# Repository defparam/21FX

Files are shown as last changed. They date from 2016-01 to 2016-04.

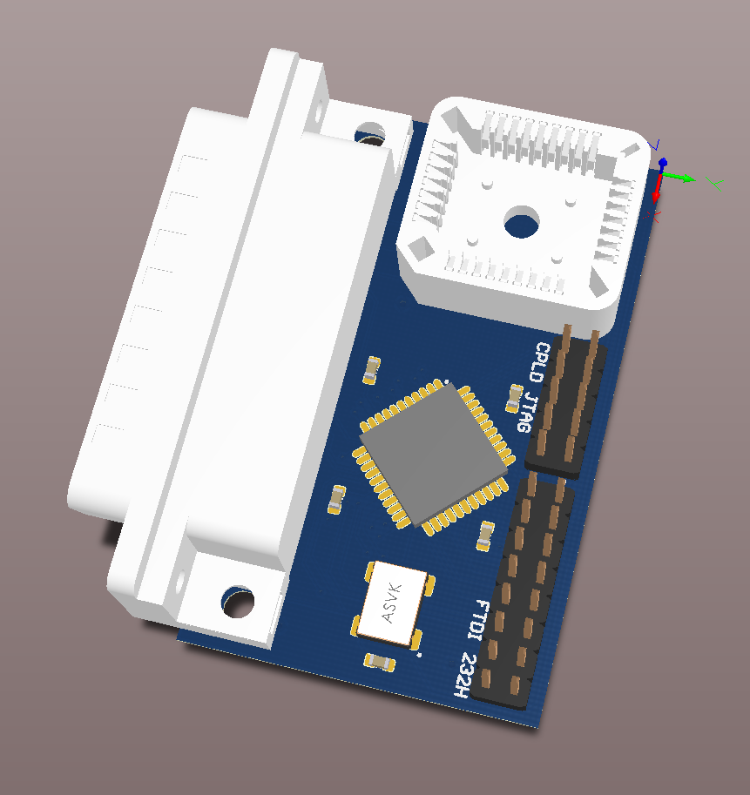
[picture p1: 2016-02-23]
photos/sh_3dt3.png

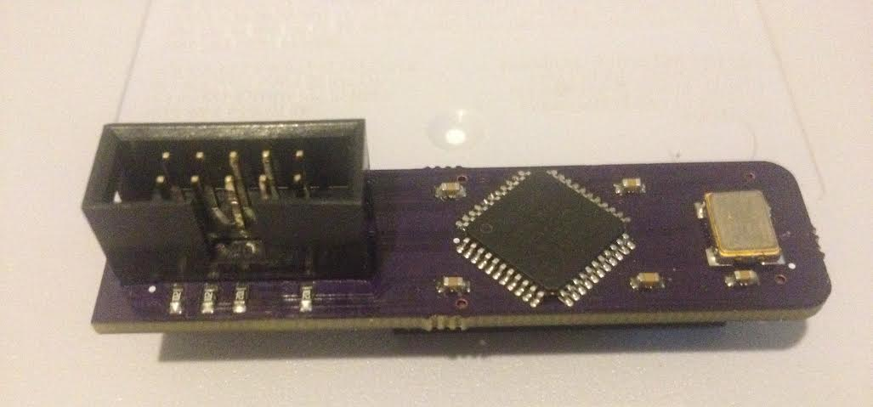
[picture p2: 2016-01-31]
photos/board_1.bmp

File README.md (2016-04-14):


# 21FX - An SNES Primary Bootloader (formerly SNES-Hook) 
This project includes Altium and verilog design files for an SNES CPLD 
expansion port to perform a simple reset hijacking and present a primary 
bootloader for the SNES to use. The bootloader is intended to be used in
conjunction with byuu's Controller Port Serial Cable for uploading
executable code into WRAM.

Updates
---------------------------------------------------------------------
4/14/2016 - REV C boards back and tested working. The boards now conform
to the new SNES expansion bridge DB-25 connector. byuu has produced the IPLROM
which is programmed to the EEPROM. Couple of issues with some power off noise
to the 232H but nothing serious

21FX - Rev C (Full Release)
---------------------------------------------------------------------
In this release we have changed the entire form factor of the board.
The board now conforms to a DB-25 connector and will mate to the new
SNES expansion bridge. We have also kept the same size CPLD and decided
to keep the IPLROM on a separate microchip 5v parallel eeprom chip. Lastly
the project no longer targets byuu's USART board. It instead has the connector
footprint for the Adafruit FT232H USB transceiver board. The IPLROM targets
all back and forth communication through this device.

SNES-Hook v1.1 REV B (Full Release)
---------------------------------------------------------------------
Updated top verilog file to include 2 more force/glitch outputs for
providing extra current strength on the glitched lines.

SNES-Hook v1.0 (Full Release)
---------------------------------------------------------------------
This a preliminary full release of SNES-Hook. In the release is the 
verilog files, Altium board design files and the quartus project which 
targets the MAX7000S CPLD on the SNES-Hook board.

@defparam

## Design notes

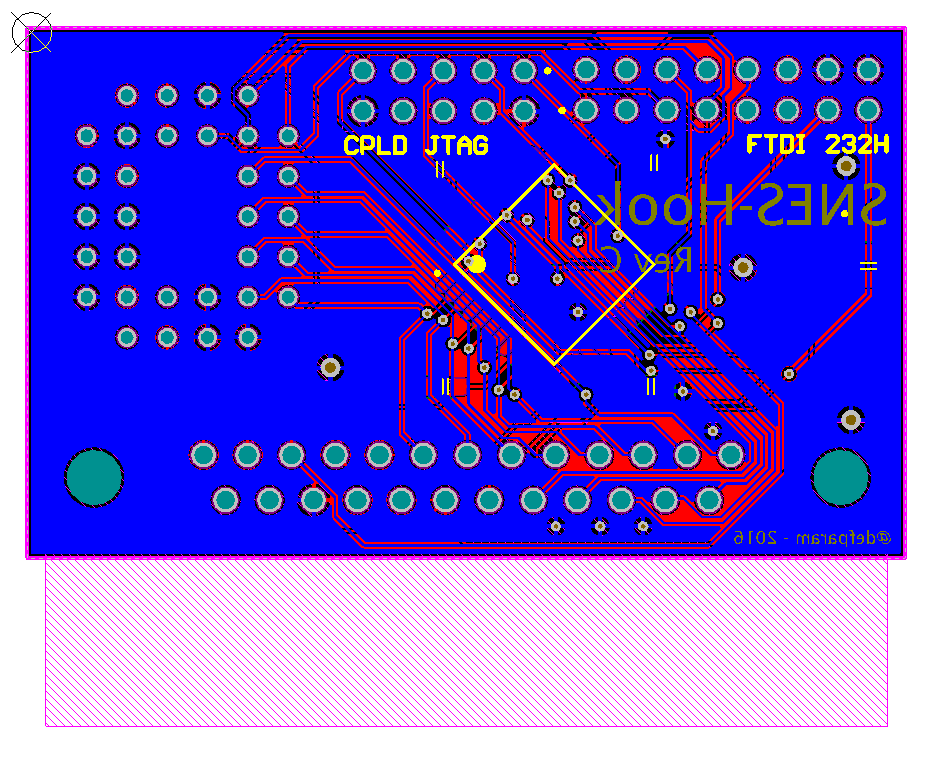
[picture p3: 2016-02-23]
photos/sh_b.png

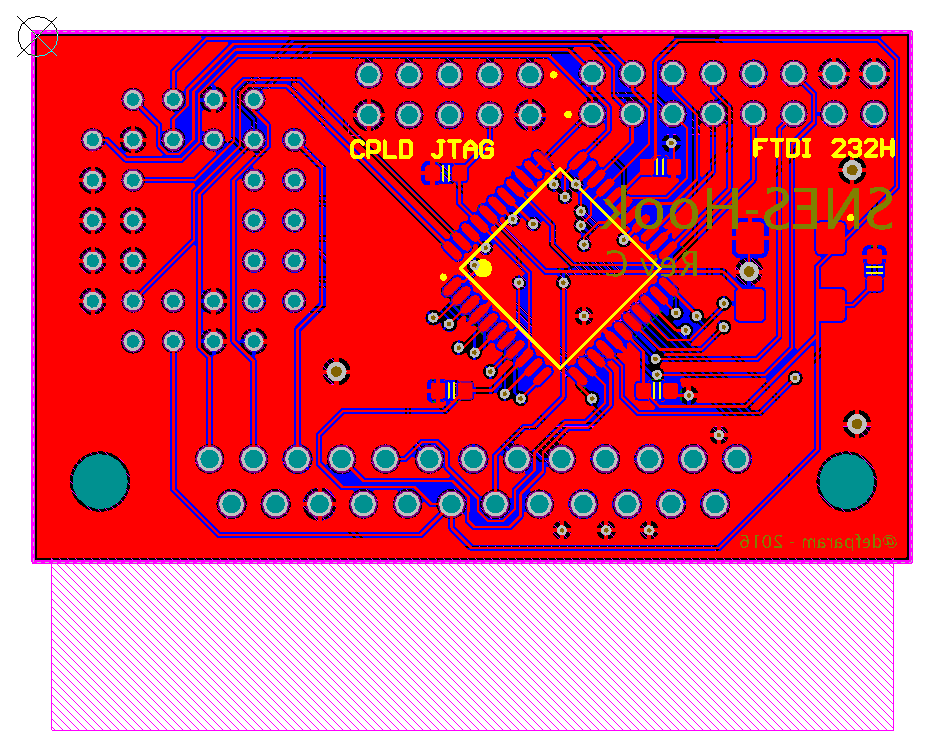
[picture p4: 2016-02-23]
photos/sh_t.png

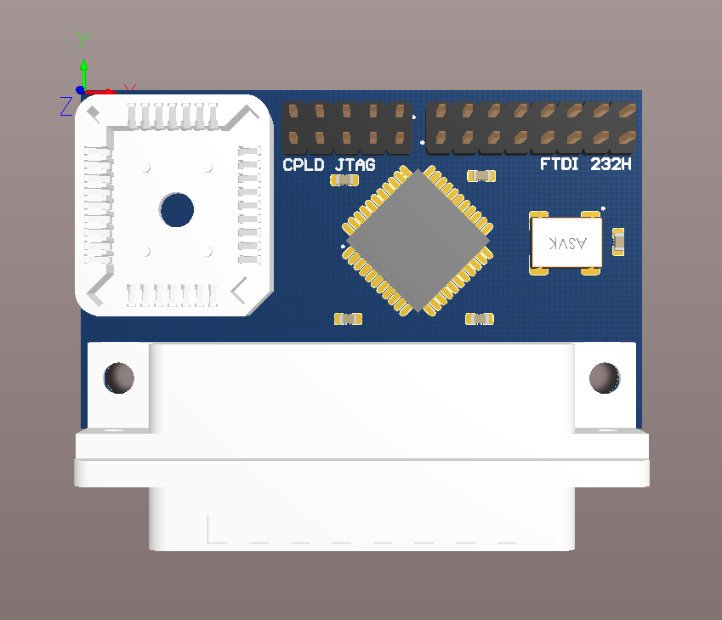
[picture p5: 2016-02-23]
photos/sh_3dt.png

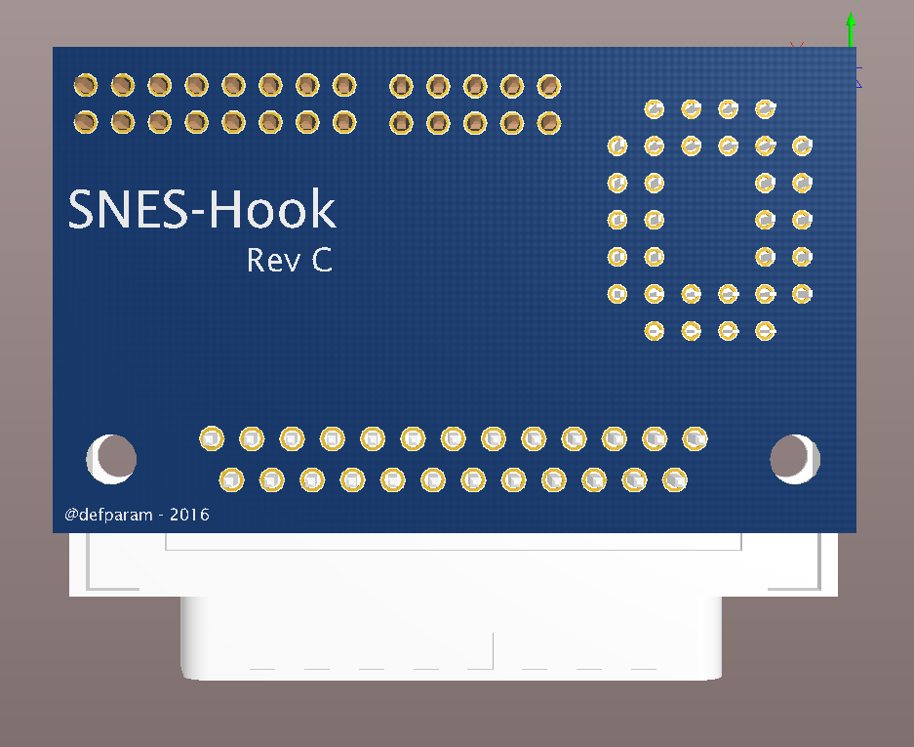
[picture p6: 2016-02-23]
photos/sh_3dt4.png

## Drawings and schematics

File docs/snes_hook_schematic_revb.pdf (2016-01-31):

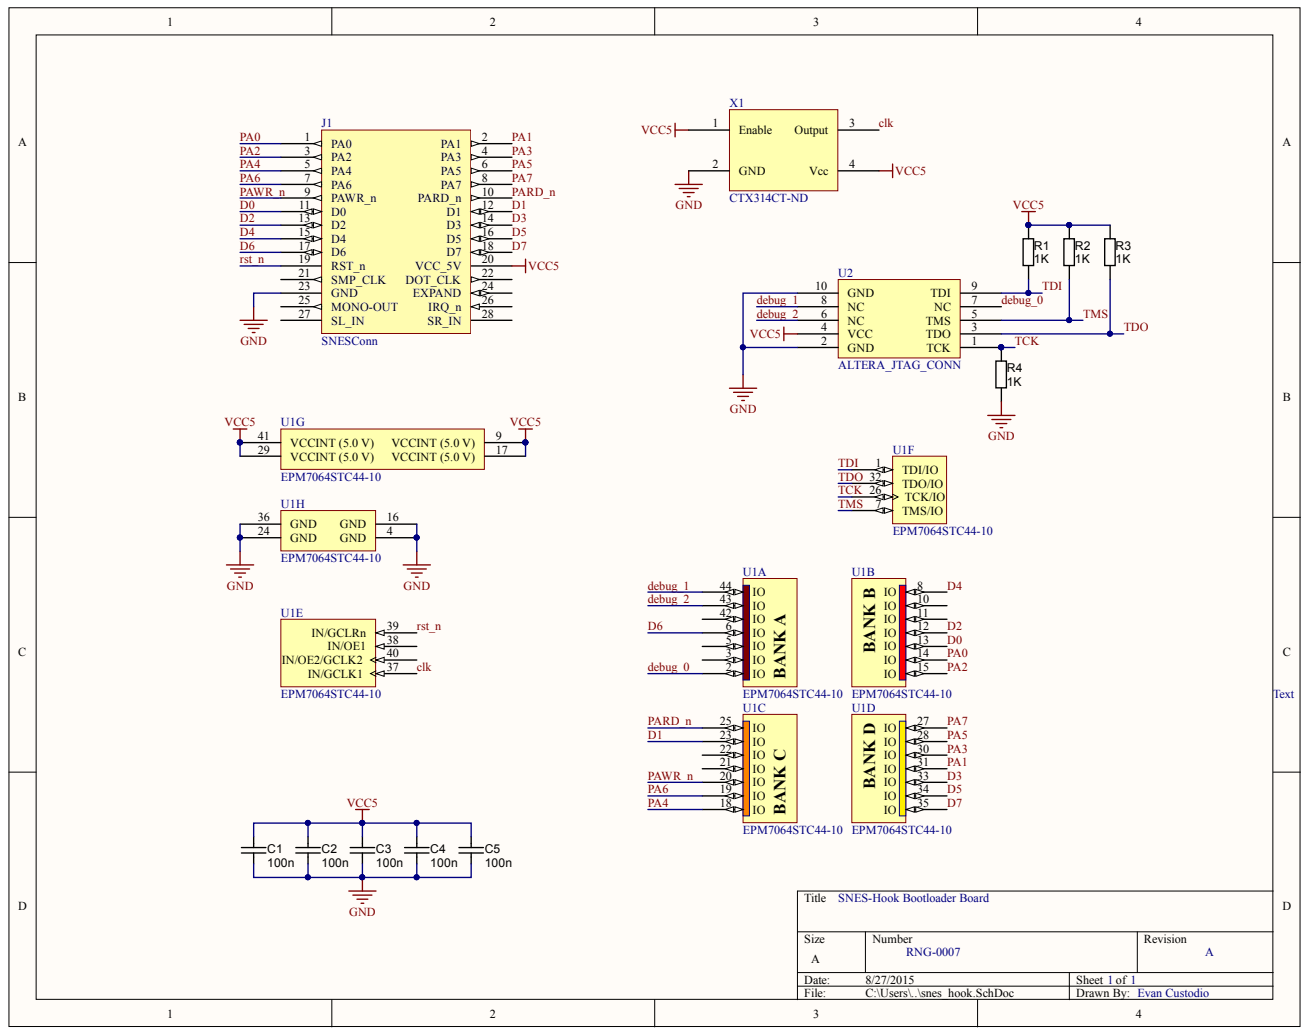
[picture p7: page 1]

SNES-Hook Bootloader Board

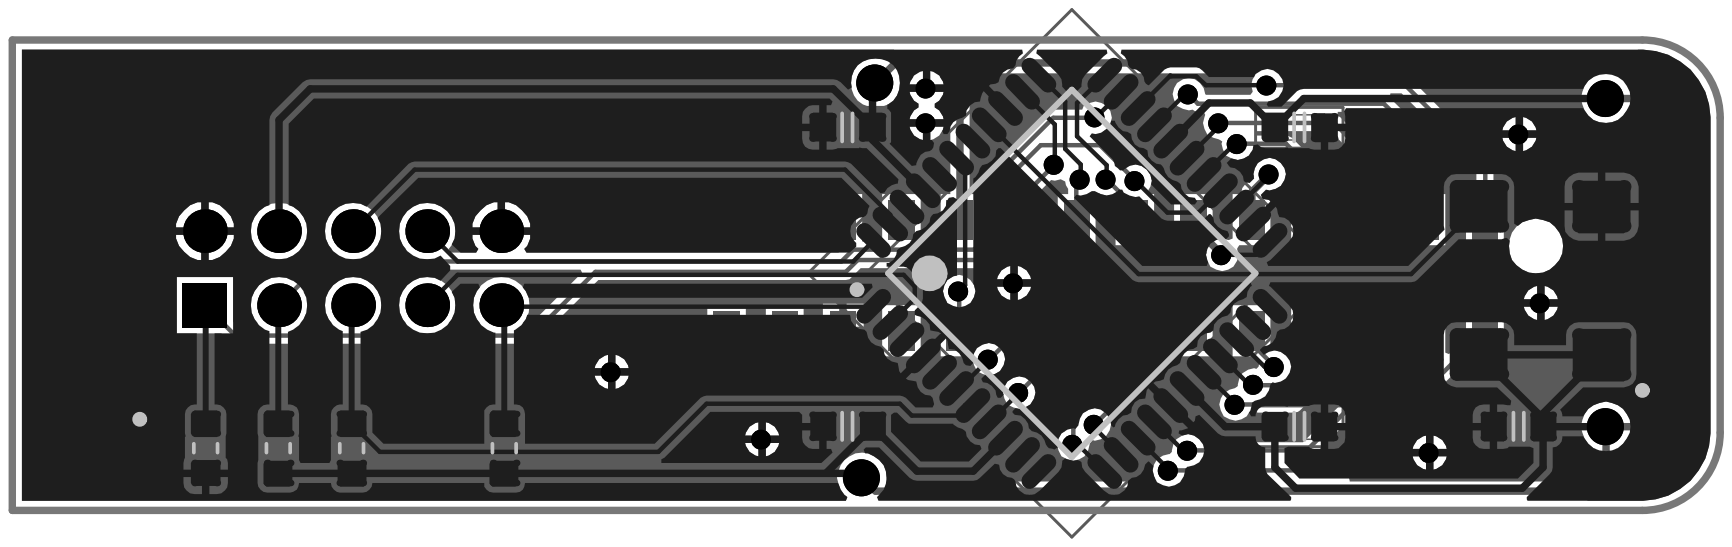
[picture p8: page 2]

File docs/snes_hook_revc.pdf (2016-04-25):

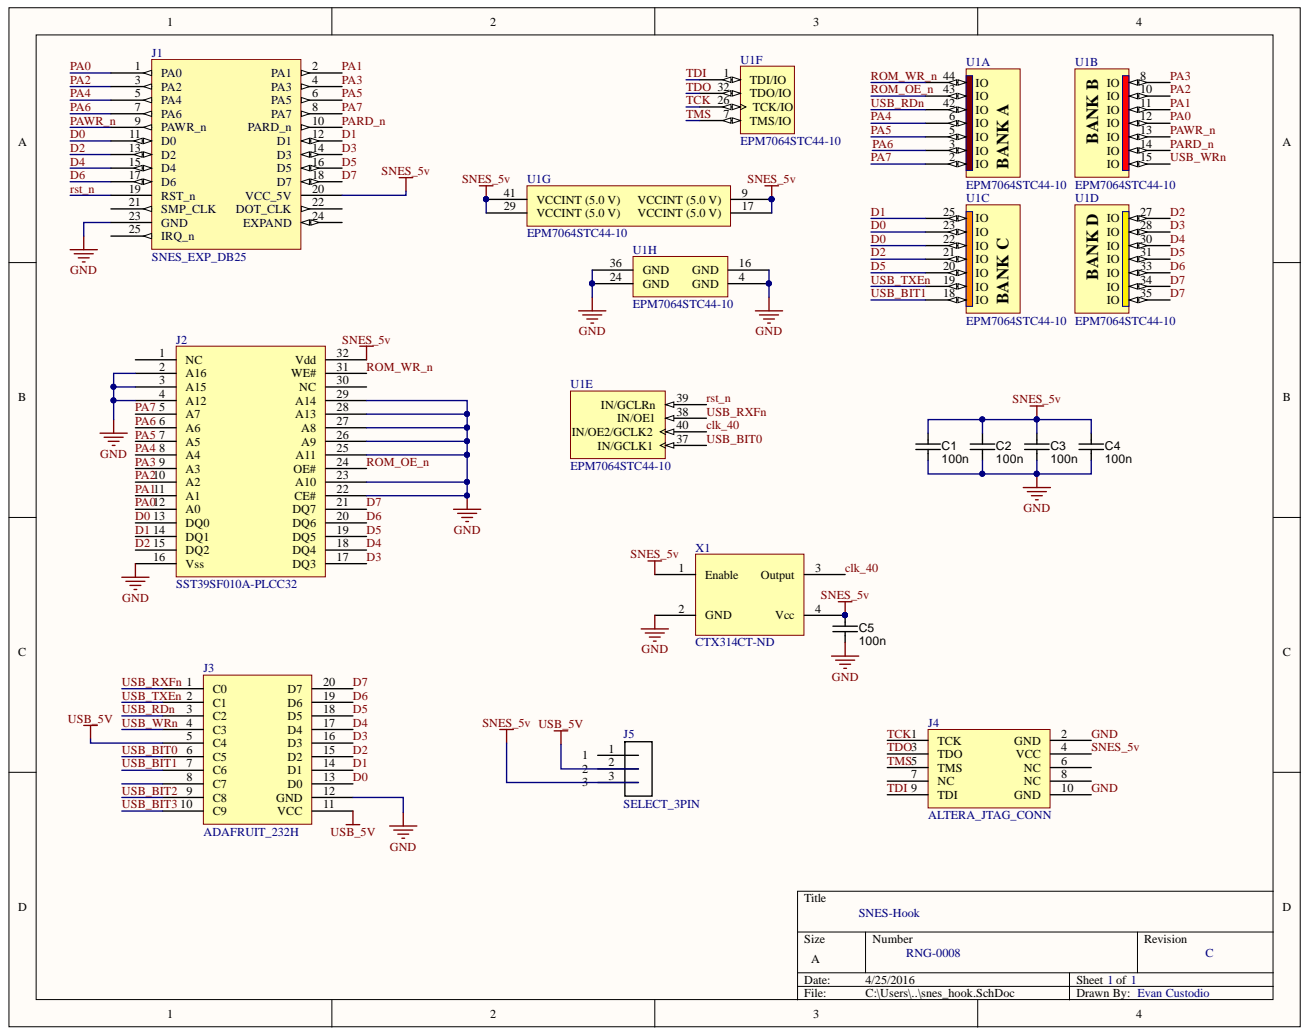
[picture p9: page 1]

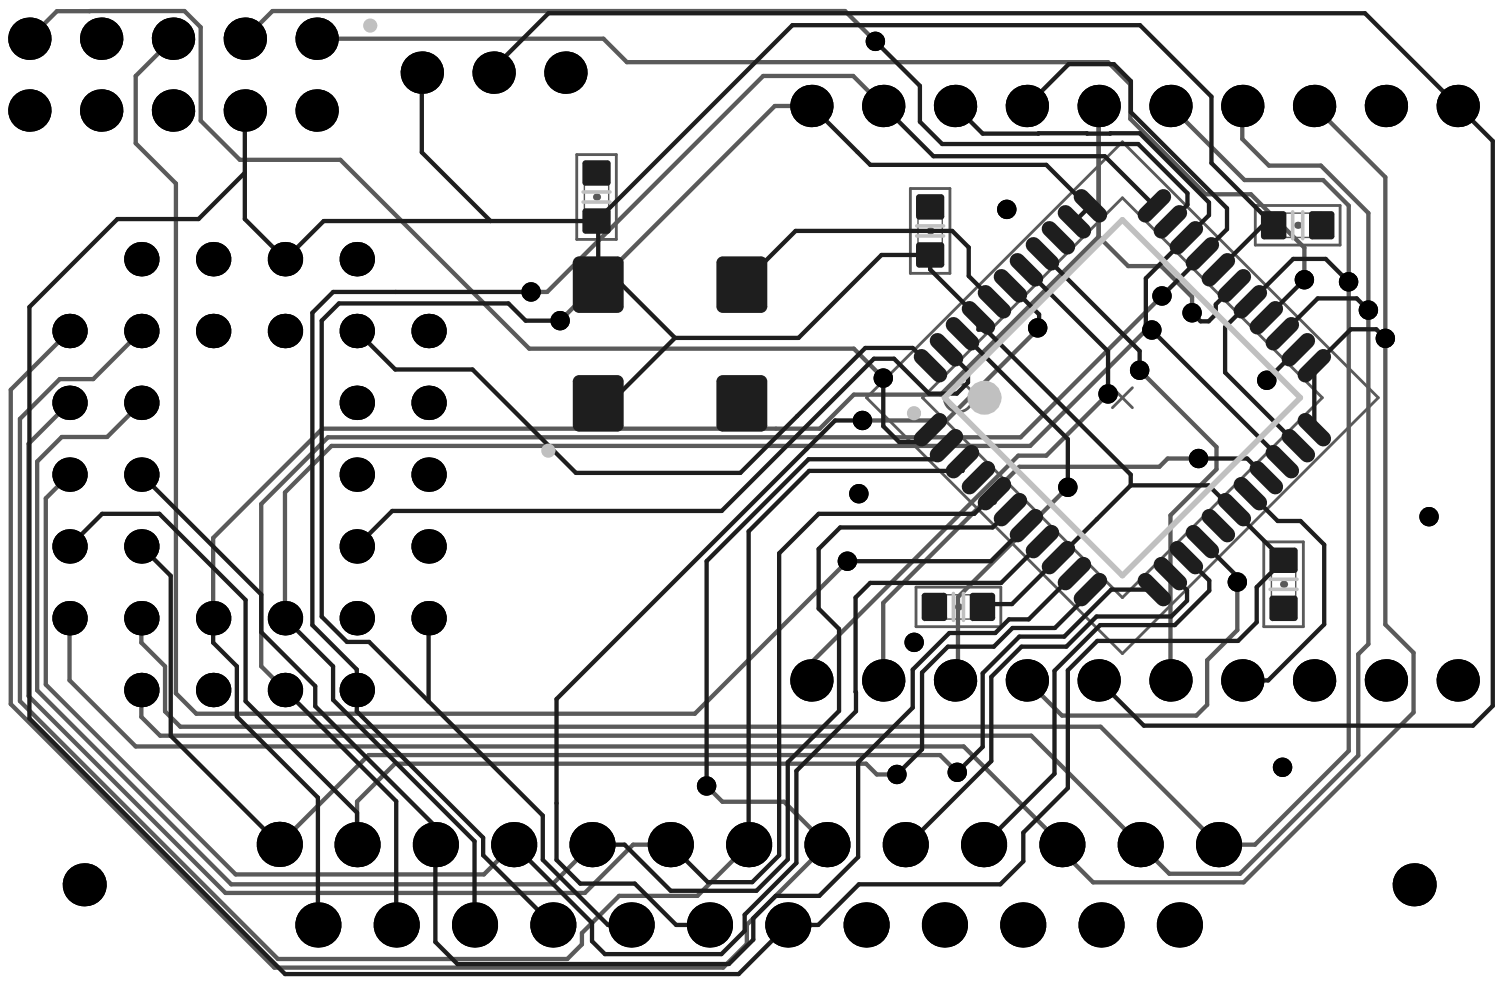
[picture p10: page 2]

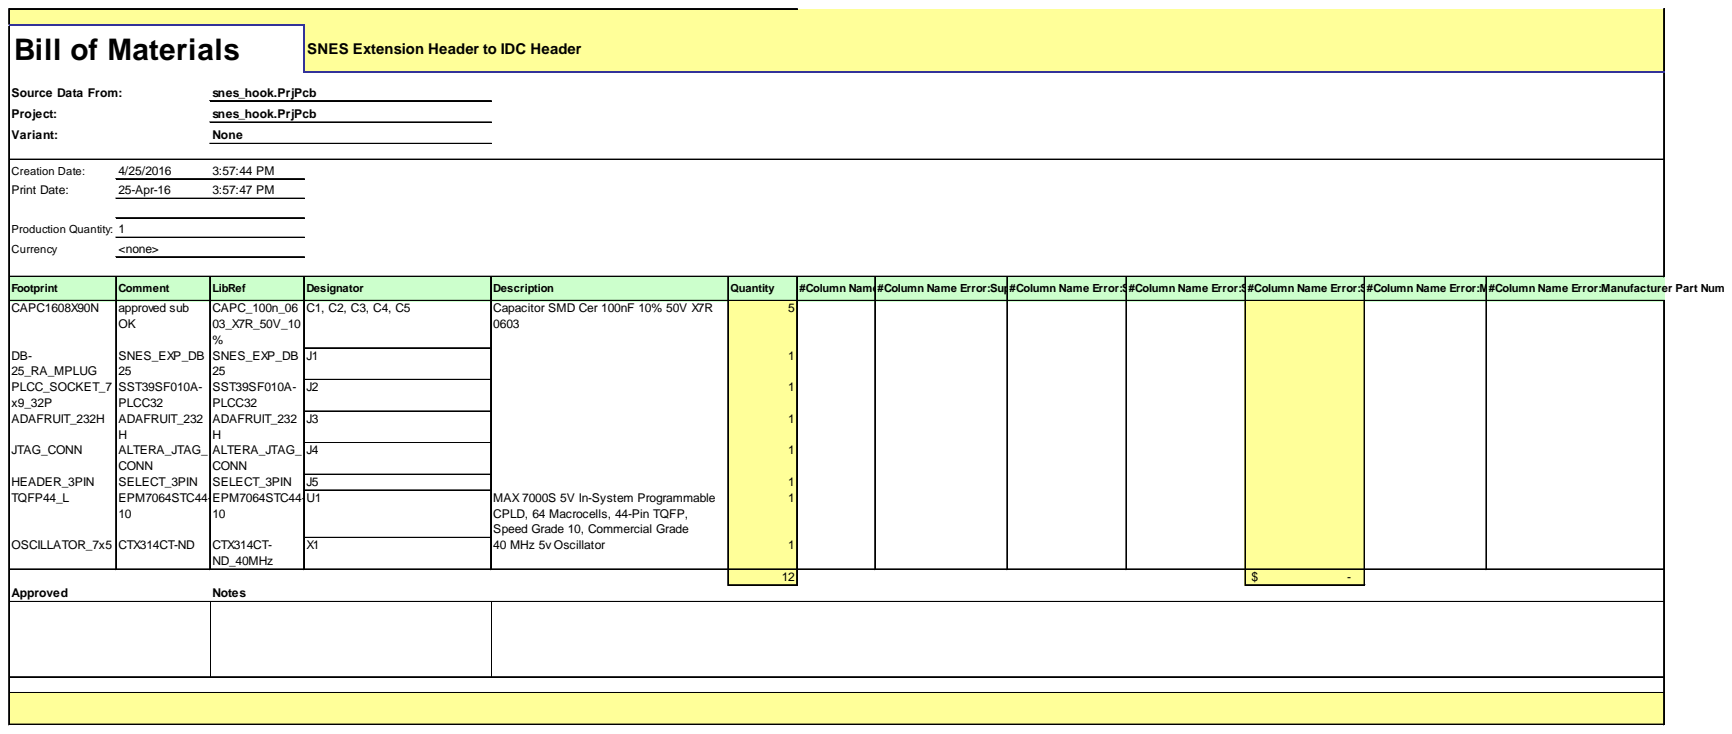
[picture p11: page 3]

CAPC1608X90N DB-25_RA_MPLUG PLCC_SOCKET_7 x9_32P ADAFRUIT_232H JTAG_CONN HEADER_3PIN TQFP44_L OSCILLATOR_7x5 | approved sub OK SNES_EXP_DB 25 SST39SF010A-PLCC32 ADAFRUIT_232 H ALTERA_JTAG_ CONN SELECT_3PIN EPM7064STC44-10 CTX314CT-ND | CAPC_100n_06 03_X7R_50V_10 % SNES_EXP_DB 25 SST39SF010A-PLCC32 ADAFRUIT_232 H ALTERA_JTAG_ CONN SELECT_3PIN EPM7064STC44-10 CTX314CT-ND_40MHz | C1, C2, C3, C4, C5 | Capacitor SMD Cer 100nF 10% 50V X7R 0603 MAX 7000S 5V In-System Programmable CPLD, 64 Macrocells, 44-Pin TQFP, Speed Grade 10, Commercial Grade 40 MHz 5v Oscillator | 5

Approved Notes | | | | | 12 | $ -

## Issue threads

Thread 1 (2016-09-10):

Gerbers

qwertymodo, 2016-09-10:
Can you post gerber files for those of us wanting to build our own?  Altium is a huge hassle just to set up the free trial long enough to export gerbers and then immediately uninstall.

defparam, 2016-09-11:
I understand your pain. I have committed gerbers/drills for 21FX and snes-exp-bridge. Sorry for not doing that in advance. The aim of all my work is to keep everything completely open. If it is any constellation all my future designs will be done in KiCad (no more Altium unless absolutely necessary).

Thanks!
Evan

qwertymodo, 2016-09-11:
Awesome, thanks. I've been wanting to build one for awhile, but Altium proved to be a barrier, not only due to it being non-free, but also the last time I tried, I wasn't able to figure it out before my trial expired.

defparam, 2016-09-11:
Yeah, I have a couple of actions here I've been delaying for a while. (due to personal life and regular work)
1) do a toploader inline version of 21FX (probably named 21FX-TopLoader or 21FX-TL) with access and control to a lot more memory map and cart pins.
2) do a refresh of the original 21FX design porting it all to KiCad (to knock down the altium barrier) and fix potential cost/EOL issues with the CPLD (perhaps move to MAX V or a Xilinx variant)

In any case, good luck!
-Evan

qwertymodo, 2016-09-11:
I actually built my own variant based on a Xilinx XC9572XL with a line driver on the data lines to handle the current requirements (as well as the 5V level shifting), but I didn't manage to get it working, and it was built in such a compact manner as to be incredibly difficult to debug. I'm hoping to build another one using the DB25 adapter that will be more debugger-friendly, and also I'm saving up to upgrade my oscilloscope to a MSO model with 16-channel logic analyser, which will help immensely. If I get it working, I'll send it your way (and if I don't, I'll probably bug you for help :P ).

defparam, 2016-09-11:
Cool! my recommendation is definitely to attach an 8 or 16 channel logic analyzer to DATA[7:0] and PA[7:0]. The bus speed is reeaaally slow (3-4 MHz) so you can probably use a very cheap chinese one and interface it using Sigrok to observe the signals out of reset and see if the CPLD is performing the glitch when you expect it. I wouldn't necessarily trust a blind port of the HDL to Xilinx without having that visibility. Your currently prototype may still be able to work :)

qwertymodo, 2016-09-12:
The 21FX gerbers are giving me errors trying to upload to OSHPark, it says the GKO (board outline) file is empty, so their upload processor can't find the board outline and refuses the upload.  The exp-bridge and snes-tap gerbers work just fine, it's just the 21FX that has issues.

defparam, 2016-09-12:
OK sorry about that, I will test when I get home (currently at work). However if you are simply re-uploading my gerbers without modification I just opened up those projects on OSHPark for share:

21FX Rev C: https://oshpark.com/shared_projects/7yV9efbf
Exp Board: https://oshpark.com/shared_projects/r3Cxllq7

Those are the OSHPark orders I used for byuu's boards so they should be OK for order. When I get home I will fix the gerbers.

Thanks,
Evan

qwertymodo, 2016-09-12:
Sweet, thanks.

Closed 2017-01-10.

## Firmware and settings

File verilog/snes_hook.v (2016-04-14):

// SNES-Hook - A tiny 5V CPLD device to hijack reset on the SNES console
//
// Copyright (C) 2015 Evan Custodio
//
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
////////////////////////////////////////////////////////////////////////////
//
// Project Name: SNES-Hook
// Author: Evan Custodio (@defparam)
//
// Module Name: snes_hook (Verilog)
//
// Interfaces: (1) 40 MHz clock in
//             (2) address bus B and databus inputs
//             (3) SNES Reset and Address bus B Read and Write (all active low)
//
// Clock Domains: (1) 40 MHz (clk) - sourced on board clock
//                (2) async RAW snes addr/data bus, (typically switches around 2MHz - 3MHz)
//
// Description: This is the top level module for the SNES-Hook CPLD. It's only job ia to come
// out of reset search for the SNES CPU access to vector $00FFFC and override the reset vector
// to point to $2184. Futhermore the CPLD sits on address range $2184-$21FF and feeds its ROM
// contents to the SNES CPU during access. A primary bootloader is intended to be stored in this
// ROM and is defined in bootcode.hex


module snes_hook (
	input                clk,
	input                rst_n,
	input [7:0]          addr,
	inout [7:0]          data,
	input                PARD_n,
	input                PAWR_n,
	input                USB_RXFn,
	input                USB_TXEn,
	output reg           USB_RDn,
	output reg           USB_WRn,
	input                USB_BIT0,
	input                USB_BIT1,
	output reg           ROM_oe_n,
	output               ROM_wr_n,	
	output reg [3:0]     glitch_force
);

   
	
	// General Variables
	reg       data_enable;
	wire      bus_latch;
	reg       bus_latch_r1;
	reg [7:0] data_out;
	reg [7:0] hist;
	reg punch;
	reg [3:0] delay_write;
	wire usb_active;
	
	// State Machine Variables and Parameters
	reg [2:0] HOOK_STATE;
	parameter ST_INIT                 = 3'h0;
	parameter ST_RST_FOUND            = 3'h1;
	parameter ST_SCAN_1               = 3'h2;
	parameter ST_SCAN_2               = 3'h3;
	parameter ST_SCAN_3               = 3'h4;
	parameter ST_IRQ_1                = 3'h5;
	parameter ST_IRQ_2                = 3'h6;

	// Forced Assignments
   assign ROM_wr_n = 1;
	assign data = (punch) ? data_out : 8'hZZ; // Bi-directional databus assignments
	assign usb_active = (~USB_BIT0 & USB_BIT1) ? 1'b1 : 1'b0;
	
	snes_bus_sync bus_sync (
		.clk(clk),                    // clock (40 MHz and reset)
		.rst_n(rst_n),
		.PA(addr),                    // RAW SNES addr bus
		.event_latch(bus_latch)       // Bus change event (detects changes in PA)
	);

	// Emulation RST vector hooking logic
	//
	// In this statemachine we assume the processor just came out of reset.
	// With that assumption we know that the first two address that will be
	// accessed is $00:FFFC and $00:FFFD. If we want to change the reset
	// vector address we need to identify the CPU cycle when the address is
	// on the data bus.

	always @(posedge clk or negedge rst_n) begin
		if (~rst_n) begin // reset regs
			HOOK_STATE   <= ST_INIT;
			bus_latch_r1 <= 1'b0;
			delay_write  <= 3'b111;
		end else begin
		   bus_latch_r1 <= bus_latch;
			
			delay_write[3]   <= (PARD_n && (HOOK_STATE != ST_INIT) && (HOOK_STATE != ST_RST_FOUND)) ? PAWR_n : 1'b1;
			delay_write[2:0] <= delay_write[3:1];
		
			if (bus_latch_r1 == 0 && bus_latch == 1) begin
				hist <= addr;
				case (HOOK_STATE)
					// This is the first state, SNES has been reset and we are waiting for the
					// processor to go to the reset vector low address
					ST_INIT: begin
						if (addr == 8'hFC) begin // address found! next wait for the high word address
							if (usb_active) HOOK_STATE <= ST_RST_FOUND; // go to the high word search state
							else HOOK_STATE <= ST_SCAN_1;
						end
					end				
					ST_RST_FOUND: begin
						if (~punch) begin
							HOOK_STATE <= ST_SCAN_1;
						end
					end				
					ST_SCAN_1: begin
						//if (addr == (hist-1) && ~USB_RXFn && usb_active) HOOK_STATE <= ST_SCAN_2;
						HOOK_STATE <= ST_SCAN_1; // Optimize out NMI search code
					end
					
					ST_SCAN_2: begin
						if (addr == (hist-1)) HOOK_STATE <= ST_SCAN_3;
						else HOOK_STATE <= ST_SCAN_1;
					end
					
					ST_SCAN_3: begin
						if (addr == (hist-1)) HOOK_STATE <= ST_IRQ_1;
						else HOOK_STATE <= ST_SCAN_1;
					end
					
					ST_IRQ_1: begin
						HOOK_STATE <= ST_IRQ_2;
						if (~punch) HOOK_STATE <= ST_SCAN_1;
					end
					
					ST_IRQ_2: begin
						if (~punch) HOOK_STATE <= ST_SCAN_1;
					end
				endcase
			end

			
		end 
	end
	
	
	
	always @(*) begin
		USB_RDn = 1;
		USB_WRn = 1;
		ROM_oe_n = 1;
		data_out = 0;
		punch = 0;
		glitch_force = 4'bZZZZ;
		if ((HOOK_STATE == ST_INIT || HOOK_STATE == ST_RST_FOUND) && (addr == 8'hFC)) begin
			punch = 1;
			data_out = 8'h84; // These lines override the vector when reset vector is detected
			glitch_force[2] = 1'b1;
			glitch_force[0] = 1'b1;
		end
		if ((HOOK_STATE == ST_RST_FOUND) && (addr == 8'hFD)) begin
		   punch = 1;
			data_out = 8'h21;
			glitch_force[3] = 1'b1;
			glitch_force[1] = 1'b1;
		end
		if ((HOOK_STATE == ST_IRQ_2 || HOOK_STATE == ST_IRQ_1) && (addr == 8'hEA)) begin
			punch = 1;
			data_out = 8'h84; // These lines override the vector when reset vector is detected
			glitch_force[2] = 1'b1;
			glitch_force[0] = 1'b1;
		end
		if ((HOOK_STATE == ST_IRQ_2) && (addr == 8'hEB)) begin
			punch = 1;
			data_out = 8'h21;
			glitch_force[3] = 1'b1;
			glitch_force[1] = 1'b1;
		end
		
		if (addr == 8'hFE && ~PARD_n) begin
			punch = 1;
			if (usb_active) data_out = {~USB_RXFn,~USB_TXEn,1'b1,5'b00000};
			else data_out = 8'b00000000;
		end
		else if (addr == 8'hFF && ~PARD_n) begin
			USB_RDn = 0;
		end
		else if (addr == 8'hFF && ~PAWR_n) begin
			USB_WRn = |delay_write[1:0];
		end
		else if (addr[7] && |addr[6:2] && ~PARD_n) begin // If there is a read to addr $2184-$21FF, return contents addressed in ROM 
			ROM_oe_n = 0;
		end
	end

	

endmodule

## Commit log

2015-08-26 Initial Check-in
    This is the first checkin for SNES-Hook. Board design files will come
    later.
2015-08-27 PCB Check-in
    - Checked in the Altium Project
    - Checked in schematic
    - Added debug signals to top level verilog
    [snes_hook.PcbDoc, snes_hook.PrjPcb, snes_hook.SchDoc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]
2015-09-24 adding photos of the latest board and modifying the bootcode
2016-01-31 Rev B board updates
    changed the top level file to add 2 new glitch outputs and tweaked some
    of the bus timing
    [snes_hook.PcbDoc, snes_hook.PrjPcb, snes_hook.SchDoc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]
2016-02-19 update branch
    [snes_hook.PcbDoc, snes_hook.PrjPcb, snes_hook.SchDoc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]
2016-02-19 Created new footprints and components. Performed initial part placement and board shaping.
    [snes_hook.PcbDoc, snes_hook.SchDoc, snes_hook_parts.PcbLib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]
2016-02-19 updated flash component with PLCC variant. Modified placement
    [snes_hook.PcbDoc, snes_hook.SchDoc, snes_hook_parts.PcbLib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]
2016-02-19 added GPIO header and re-placed components
    [snes_hook.PcbDoc, snes_hook.SchDoc, snes_hook_parts.PcbLib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]
2016-02-22 Changed the verilog to accomodate modeling the 232H. Placed and routed 99% of the board.
    [snes_hook.PcbDoc, snes_hook.PrjPcb, snes_hook.SchDoc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]
2016-02-23 finishing touches
    [snes_hook.PcbDoc, snes_hook.SchDoc]
2016-02-26 Redoing placement and layout. Issue found (mismatched pins for DB-25)
    [snes_hook.PcbDoc, snes_hook.PrjPcb, snes_hook.SchDoc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]
2016-02-28 latest changes before fab
    [snes_hook.PcbDoc, snes_hook.PrjPcb, snes_hook.SchDoc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]
2016-09-11 Added gerbers for extra open-sourcy-ness :)
    [snes_hook.GBL, snes_hook.GBO, snes_hook.GBP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]

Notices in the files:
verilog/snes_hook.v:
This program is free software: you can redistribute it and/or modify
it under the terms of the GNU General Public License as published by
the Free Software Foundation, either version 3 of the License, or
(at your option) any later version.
